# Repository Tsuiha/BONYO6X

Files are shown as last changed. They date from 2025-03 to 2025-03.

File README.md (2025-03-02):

# BONYO6X

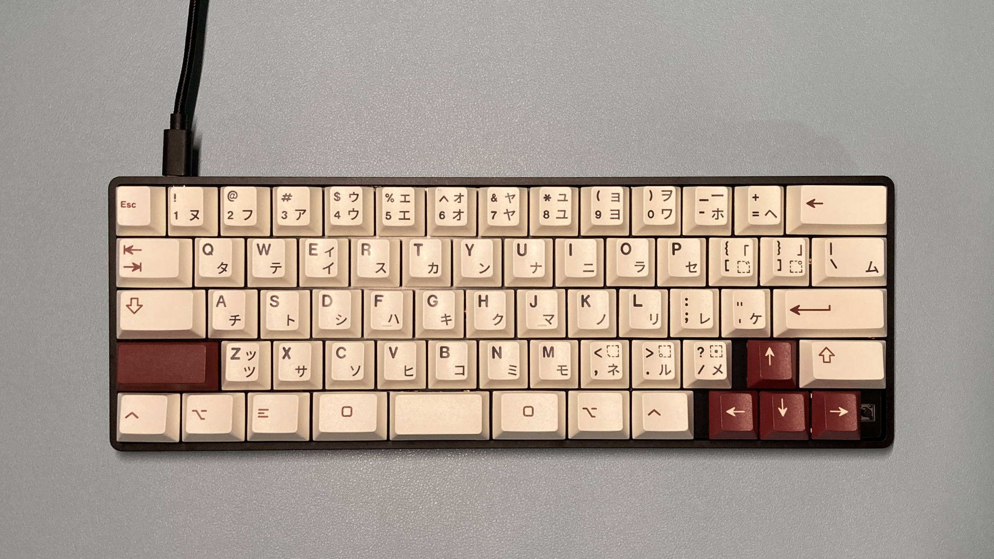
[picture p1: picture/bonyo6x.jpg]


　BONYO6Xは60%キーボードの汎用ケース、所謂Poker, GH60, DZ60等に対応したケースと互換性のあるPCBです。
 
　他人でも初見で使える, 自分でも不満なく使える, ことをコンセプトとしています。基本的なANSIは崩さずにカスタマイズ性も確保した構成を目指した、特化型でなく器用貧乏型のキーボードです。
 
　使用用途は実務からラフな普段使いまで, 一台で可もなく不可もなく, 満遍なくこなすことを想定しています。

　リポジトリに設計データが公開されています。 自由にしてください。

　[noteでも紹介しています](https://note.com/tsuiha/m/m13bdadaac60e)

## キー配置

　ANSIをベースに私の趣味を加え以下のようにカスタムしたものになります。

・2U Shift Layout  
　Row StaggeredよりもColumn StaggeredやOrtholinearが好きなこともあり、オフセット量の揃った2U Shiftの方が好みです。

・1.5U, 2U, 1.5U Thumb Cluster  
　2U スペースキーの左右に1.5U Modキーを配置し、レイヤー移動を前提とした配列としています。

・Arrow Keys  
　Arrow KeysがTop Layerにあると痒い時に手が届きます。DZ60系の詰めた配列ではなく、1.75U Shiftを端に、Arrow Keysはその内側に配置しています。

・Tactile Switch  
　キーボード右下にタクトスイッチを搭載可能です。マイクミュート, スクリーンショット, リプレイの保存 等、キースイッチと独立したFunctionキーとして使用できます。

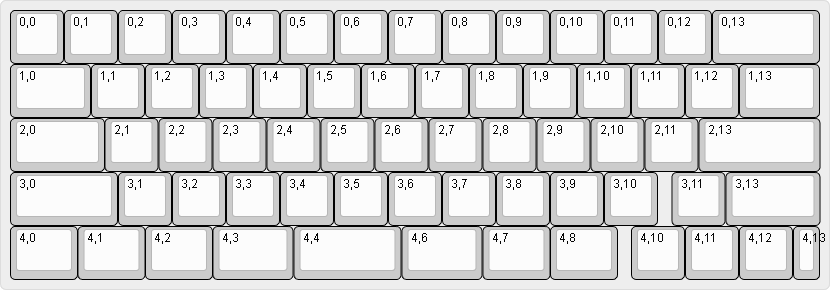
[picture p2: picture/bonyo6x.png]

画像はkeyboard-layout-editor.comにて作成しました。

## LED
　LEDが2個搭載可能です。デフォルトでは現在のレイヤーに対応して発光色が変化します。
　発光強度や色、光らせ方はファームウェアを改変し変更することができます。

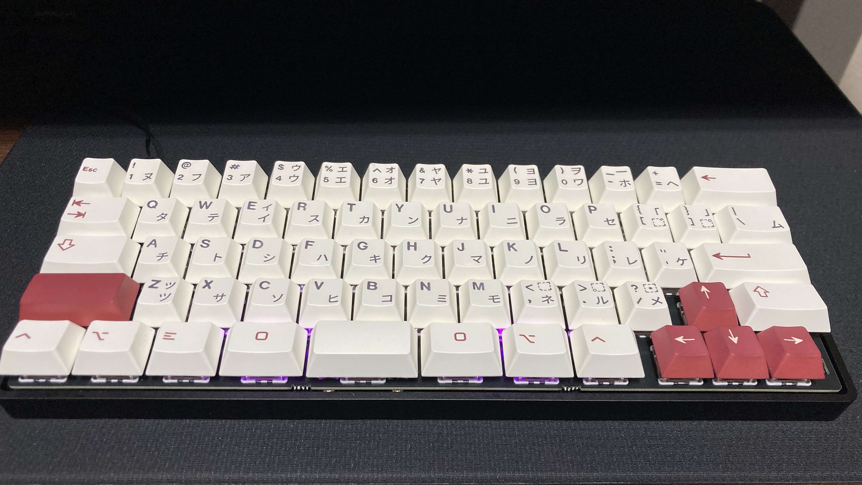
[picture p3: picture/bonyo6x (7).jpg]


## タクタイルスイッチ
　タクタイルスイッチが1個搭載可能です。ケース高に応じて高さのあったスイッチを使用してください。フローティングデザインのケースでは7mmのものを、通常デザインのケースでは11mmのものを画像では使用しています。

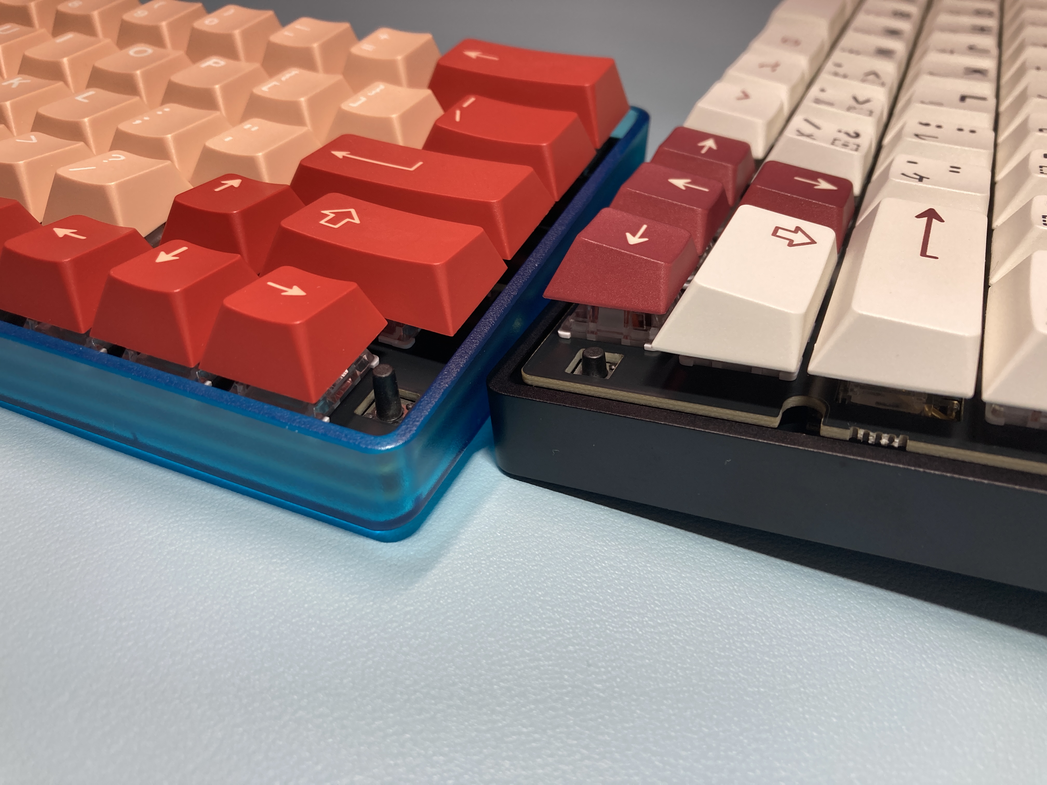
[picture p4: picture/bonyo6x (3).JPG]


# 組み立て

## PCB & Switch Plate 
　誰かが製造したものを入手するか、公開されている設計データから自身で製造ください。JLCPCBを使用する際は発注データが公開されています。

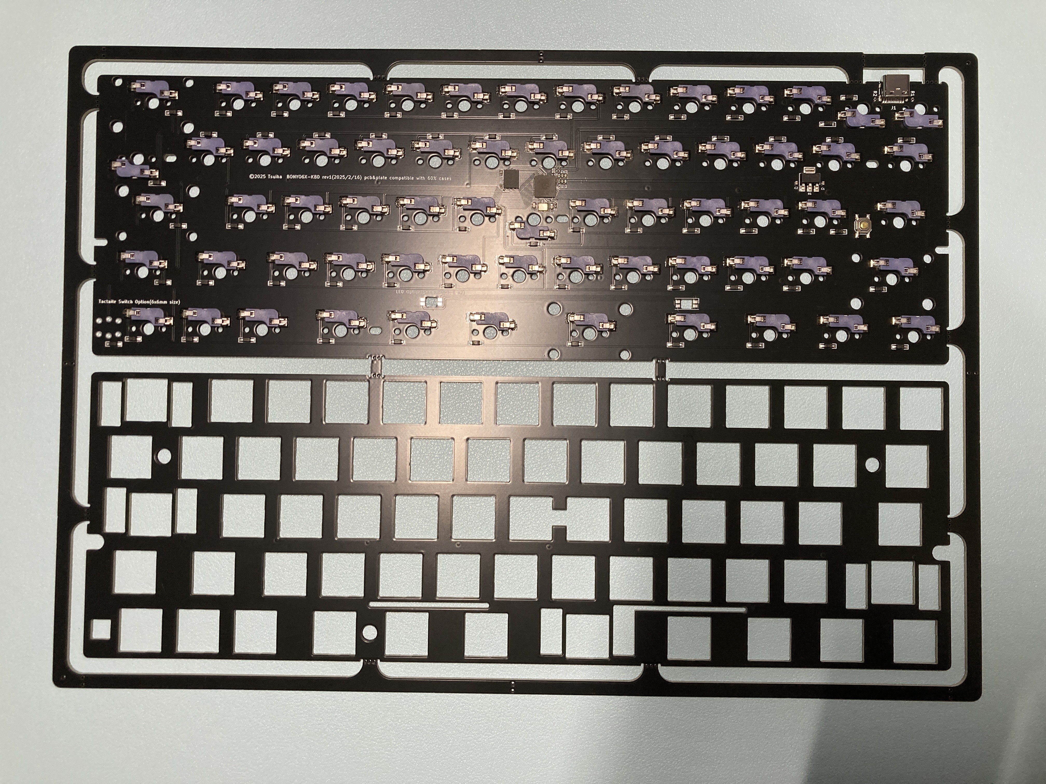
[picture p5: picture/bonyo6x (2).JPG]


## LED SK6812MINI-E x2
　オプションでLEDを取り付けることができます。



## Tactile Switch x1
　オプションでタクトスイッチを取り付けることができます。6x6mmサイズの2pinまたは4pinのものを使用することができます。





## qmk-vial
　ファームウェアにはqmk-vialを使用しています。

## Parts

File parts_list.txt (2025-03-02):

-Examples of required parts are shown below. Other compatible parts are acceptable.

Switch Plate x1
PCB x1
-There is published kicad data here

MX Switch and Keycap x 65 

Poker compatible case
-Please check the compatibility with the case on your own.

Tactile Switch x1 *option
-6x6mm type with 2 or 4 pins can be used. You can choose any height.

LED SK6812MINI-E x2 *option

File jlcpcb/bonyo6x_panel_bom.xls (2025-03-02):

Comment | Designator | Footprint | JLCPCB Part #
HRO_TYPE-C-31-M-12 | J1 | USB_C_Receptacle_HRO_TYPE-C-31-M-12 | C165948
AMS1117-3.3 | U1 | SOT-223 | C6186
rp2040 | U2 | QFN-56-1EP_7x7mm_P0.4mm_EP3.2x3.2mm | C2040
W25Q128JVPIQ | U3 | WSON-8-1EP_6x5mm_P1.27mm_EP3.4x4.3mm | C190862
Crystal_GND24 | Y1 | Crystal_SMD_3225-4Pin_3.2x2.5mm | C9002
5.1kohm | R1-2 | C_0402_1005Metric | C25905
27ohm | R3-4 | C_0402_1005Metric | C25100
1kohm | R5-6 | C_0402_1005Metric | C11702
10uF | C1-2 | C_0402_1005Metric | C315248
100nF | C3,C4,C5,C6,C9 | C_0402_1005Metric | C1525
1uF | C7-8 | C_0402_1005Metric | C52923
30pF | C10-11 | C_0603_1608Metric | C1658
SW_BOOT | SW_boot1 | SW_SPST_SKQG_WithStem | C318884
diode | D1-66 | Diode_SMD_noname | C81598
hotswapsocket | SW1-65 | CherryMX_Hotswap | CPG151101S11-16

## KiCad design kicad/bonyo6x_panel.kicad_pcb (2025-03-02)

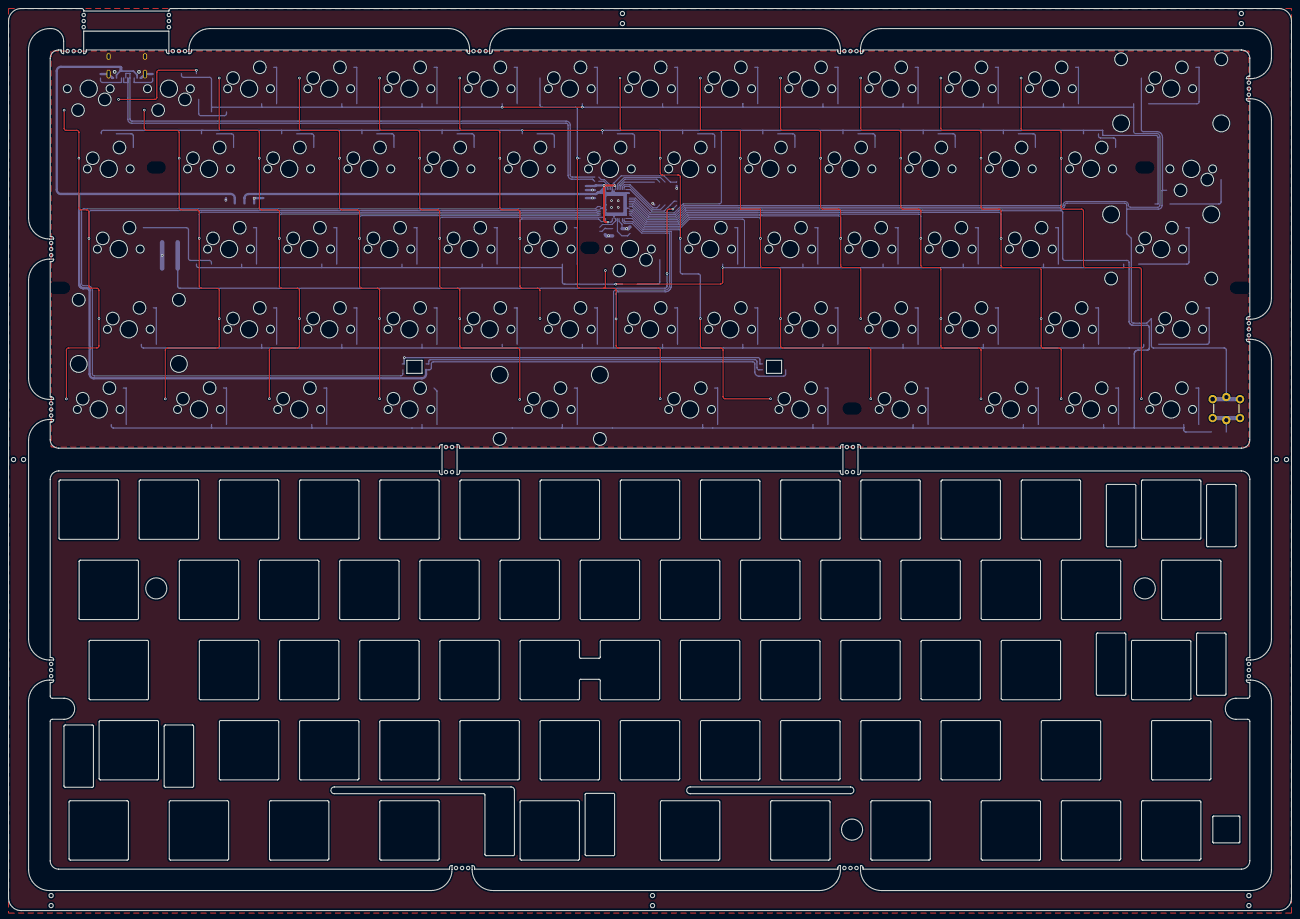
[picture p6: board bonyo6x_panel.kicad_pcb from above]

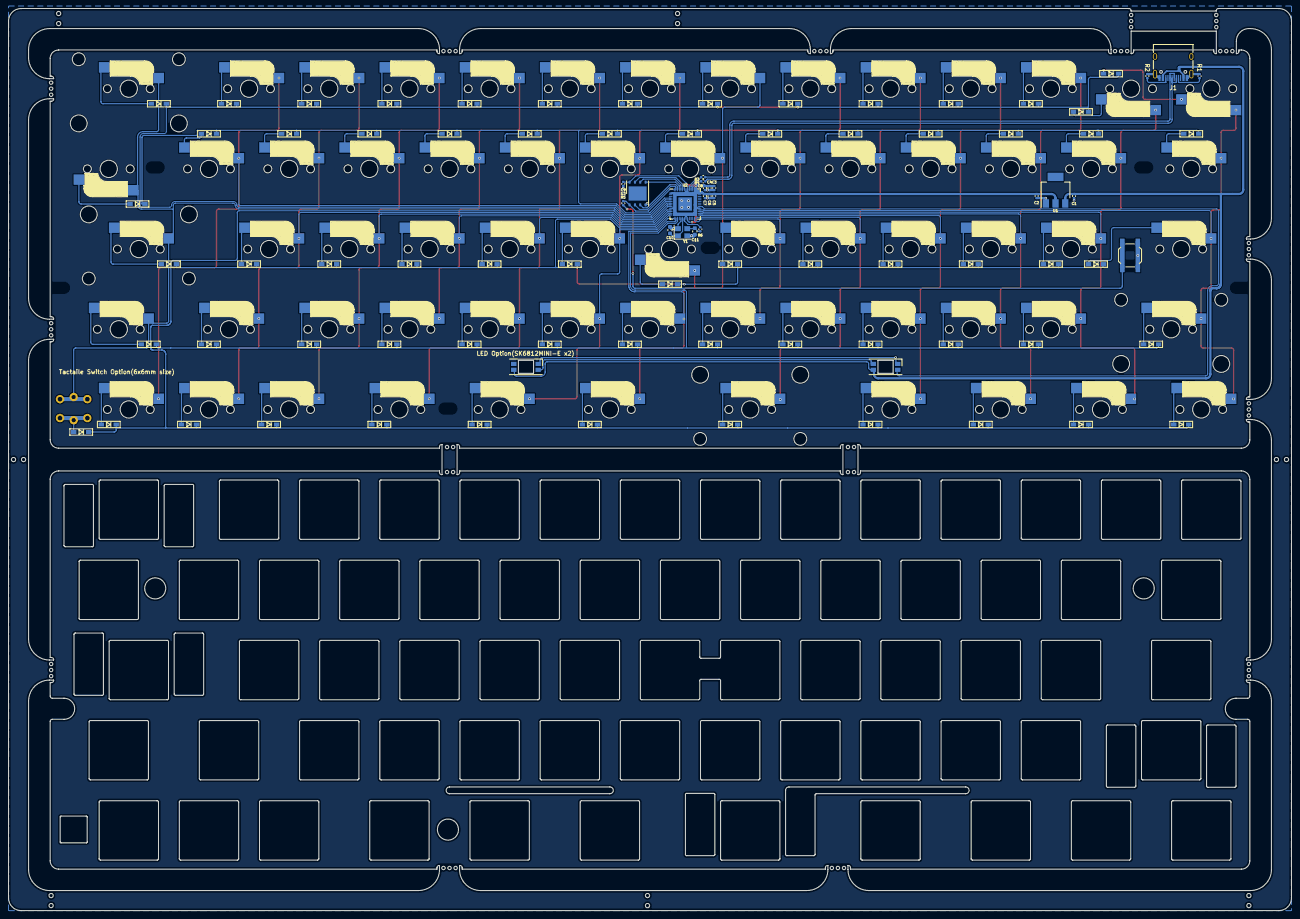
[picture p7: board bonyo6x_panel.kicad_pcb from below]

Board: 2 copper layers, 304.8 x 214.3 mm, 220 parts (25 on the bottom side), 107 nets.

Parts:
C1, C2: 10u; C_0402_1005Metric
C3, C4, C5, C6, C9: 100n; C_0402_1005Metric
C7, C8: 1u; C_0402_1005Metric
C10, C11: 30p; C_0603_1608Metric
D1, D2, D3, D4, D5, D6, D7, D8, D9, D10, D11, D12, D13, D14, D15, D16, D17, D18, D19, D20, D21, D22, D23, D24, D25, D26, D27, D28, D29, D30, D31, D32, D33, D34, D35, D36, D37, D38, D39, D40, D41, D42, D43, D44, D45, D46, D47, D48, D49, D50, D51, D52, D53, D54, D55, D56, D57, D58, D59, D60, D61, D62, D63, D64, D65, D66: D; Diode_SMD_noname
J1: USB_C_Receptacle; USB_C_Receptacle_HRO_TYPE-C-31-M-12
LED1, LED2: YS-SK6812MINI-E
R1, R2: 5.1k; C_0402_1005Metric
R3, R4: 27; C_0402_1005Metric
R5, R6: 1k; C_0402_1005Metric
SW1, SW2#2, SW3, SW4#2, SW5, SW6, SW7#2, SW8#2, SW9#2, SW10, SW11#2, SW12, SW13#2, SW16, SW17, SW18#2, SW19, SW20, SW21#2, SW22#2, SW23, SW24, SW25, SW26, SW27, SW30, SW31, SW32, SW33#2, SW34, SW35, SW36, SW37#2, SW38#2, SW39, SW40#2, SW43#2, SW44, SW45#2, SW46, SW47, SW48#2, SW49, SW50#2, SW51#2, SW52#2, SW53, SW63, SW64#2, SW65: SW_PUSH; CherryMX_Hotswap
SW1#2, SW2, SW3#2, SW4, SW5#2, SW6#2, SW7, SW8, SW9, SW10#2, SW11, SW12#2, SW13, SW16#2, SW17#2, SW18, SW19#2, SW20#2, SW21, SW22, SW23#2, SW24#2, SW25#2, SW26#2, SW27#2, SW30#2, SW31#2, SW32#2, SW33, SW36#2, SW37, SW38, SW39#2, SW40, SW43, SW44#2, SW45, SW46#2, SW47#2, SW48, SW49#2, SW50, SW51, SW52, SW53#2, SW63#2, SW64, SW65#2: SW_PUSH; SW_Hole_1u
SW14: SW_PUSH_2; SW_Hole_2u
SW14#2: SW_PUSH_2; CherryMX_Hotswap_2u
SW15, SW28, SW58#2, SW60, SW60#3: SW_PUSH_15; SW_Hole_1u
SW15#2, SW28#2, SW58, SW60#2: SW_PUSH_15; CherryMX_Hotswap_1.5u
SW29, SW54#2: SW_PUSH_175; CherryMX_Hotswap_1.75u
SW29#2, SW54: SW_PUSH_175; SW_Hole_1u
SW41: SW_PUSH_225; CherryMX_Hotswap_2u_r
SW41#2, SW42: SW_PUSH_225; SW_Hole_2u
SW42#2: SW_PUSH_225; CherryMX_Hotswap_2u
SW55, SW56#2, SW57, SW61, SW62#2: SW_PUSH_125; CherryMX_Hotswap_1.25u
SW55#2, SW56, SW57#2, SW61#2, SW62: SW_PUSH_125; SW_Hole_1u
SW59: SW_PUSH_2; CherryMX_Hotswap_2u_r
SW_boot1: SW_BOOT; SW_SPST_SKQG_WithStem
SW_tact1: SW_PUSH; tactileforkh60
U1: AMS1117-3.3; SOT-223
U2: RP2040; QFN-56-1EP_7x7mm_P0.4mm_EP3.2x3.2mm
U3: W25Q128JVS; WSON-8-1EP_6x5mm_P1.27mm_EP3.4x4.3mm
Y1: Crystal_GND24; Crystal_SMD_3225-4Pin_3.2x2.5mm

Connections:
+1V1: C3.1, C4.1, C8.1, U2.23 (DVDD), U2.45 (VREG_VOUT), U2.50 (DVDD)
+3V3: C2.1, C5.1, C6.1, C7.1, C9.1, U1.2 (VO), U2.1 (IOVDD), U2.10 (IOVDD), U2.22 (IOVDD), U2.33 (IOVDD), U2.42 (IOVDD), U2.43 (ADC_AVDD), U2.44 (VREG_IN), U2.48 (USB_VDD), U2.49 (IOVDD), U3.8 (VCC)
+5V: C1.1, J1.A4 (VBUS), J1.A9 (VBUS), J1.B4 (VBUS), J1.B9 (VBUS), LED1.1 (VDD), LED2.1 (VDD), U1.3 (VI)
/QSPI_SCLK: U2.52 (QSPI_SCLK), U3.6 (CLK)
/QSPI_SD0: U2.53 (QSPI_SD0), U3.5 (DI(IO0))
/QSPI_SD1: U2.55 (QSPI_SD1), U3.2 (DO(IO1))
/QSPI_SD2: U2.54 (QSPI_SD2), U3.3 (IO2)
/QSPI_SD3: U2.51 (QSPI_SD3), U3.7 (IO3)
/QSPI_SS: R5.1, U2.56 (QSPI_SS), U3.1 (~CS)
/USB_D+: J1.A6 (D+), J1.B6 (D+), R3.2
/USB_D-: J1.A7 (D-), J1.B7 (D-), R4.2
/XIN: C10.2, U2.20 (XIN), Y1.1
/XOUT: R6.1, U2.21 (XOUT)
/~USB_BOOT: R5.2, SW_boot1.1
GND: C1.2, C2.2, C3.2, C4.2, C5.2, C6.2, C7.2, C8.2, C9.2, C10.1, C11.2, J1.A1 (GND), J1.A12 (GND), J1.B1 (GND), J1.B12 (GND), J1.S1 (SHIELD), LED1.3 (VSS), LED2.3 (VSS), R1.1, R2.1, SW_boot1.2, U1.1 (GND), U2.19 (TESTEN), U2.57 (GND), U3.4 (GND), Y1.2, Y1.4
LED: LED1.4 (DIN), U2.34 (GPIO22)
unnamed: C11.1, R6.2, Y1.3
unnamed: D1.2 (A), SW1.1
unnamed: D2.2 (A), SW2#2.1
unnamed: D3.2 (A), SW3.2
unnamed: D4.2 (A), SW4#2.2
unnamed: D5.2 (A), SW5.2
unnamed: D6.2 (A), SW6.2
unnamed: D7.2 (A), SW7#2.2
unnamed: D8.2 (A), SW8#2.2
unnamed: D9.2 (A), SW9#2.2
unnamed: D10.2 (A), SW10.2
unnamed: D11.2 (A), SW11#2.2
unnamed: D12.2 (A), SW12.2
unnamed: D13.2 (A), SW13#2.2
unnamed: D14.2 (A), SW14#2.2
unnamed: D15.2 (A), SW15#2.2
unnamed: D16.2 (A), SW16.2
unnamed: D17.2 (A), SW17.2
unnamed: D18.2 (A), SW18#2.2
unnamed: D19.2 (A), SW19.2
unnamed: D20.2 (A), SW20.2
unnamed: D21.2 (A), SW21#2.2
unnamed: D22.2 (A), SW22#2.2
unnamed: D23.2 (A), SW23.2
unnamed: D24.2 (A), SW24.2
unnamed: D25.2 (A), SW25.2
unnamed: D26.2 (A), SW26.2
unnamed: D27.2 (A), SW27.2
unnamed: D28.2 (A), SW28#2.1
unnamed: D29.2 (A), SW29.2
unnamed: D30.2 (A), SW30.2
unnamed: D31.2 (A), SW31.2
unnamed: D32.2 (A), SW32.2
unnamed: D33.2 (A), SW33#2.2
unnamed: D34.2 (A), SW34.2
unnamed: D35.2 (A), SW35.1
unnamed: D36.2 (A), SW36.2
unnamed: D37.2 (A), SW37#2.2
unnamed: D38.2 (A), SW38#2.2
unnamed: D39.2 (A), SW39.2
unnamed: D40.2 (A), SW40#2.2
unnamed: D41.2 (A), SW41.2
unnamed: D42.2 (A), SW42#2.2
unnamed: D43.2 (A), SW43#2.2
unnamed: D44.2 (A), SW44.2
unnamed: D45.2 (A), SW45#2.2
unnamed: D46.2 (A), SW46.2
unnamed: D47.2 (A), SW47.2
unnamed: D48.2 (A), SW48#2.2
unnamed: D49.2 (A), SW49.2
unnamed: D50.2 (A), SW50#2.2
unnamed: D51.2 (A), SW51#2.2
unnamed: D52.2 (A), SW52#2.2
unnamed: D53.2 (A), SW53.2
unnamed: D54.2 (A), SW54#2.2
unnamed: D55.2 (A), SW55.2
unnamed: D56.2 (A), SW56#2.2
unnamed: D57.2 (A), SW57.2
unnamed: D58.2 (A), SW58.2
unnamed: D59.2 (A), SW59.2
unnamed: D60.2 (A), SW60#2.2
unnamed: D61.2 (A), SW61.2
unnamed: D62.2 (A), SW62#2.2
unnamed: D63.2 (A), SW63.2
unnamed: D64.2 (A), SW64#2.2
unnamed: D65.2 (A), SW65.2
unnamed: D66.2 (A), SW_tact1.2
unnamed: J1.A5 (CC1), R1.2
unnamed: J1.B5 (CC2), R2.2
unnamed: LED1.2 (DOUT), LED2.4 (DIN)
unnamed: R4.1, U2.46 (USB_DM)
unnamed: R3.1, U2.47 (USB_DP)
c0: SW1.2, SW15#2.1, SW29.1, SW42#2.1, SW55.1, U2.32 (GPIO21)
c1: SW2#2.2, SW16.1, SW30.1, SW43#2.1, SW56#2.1, U2.31 (GPIO20)
c2: SW3.1, SW17.1, SW31.1, SW44.1, SW57.1, U2.30 (GPIO19)
c3: SW4#2.1, SW18#2.1, SW32.1, SW45#2.1, SW58.1, U2.29 (GPIO18)
c4: SW5.1, SW19.1, SW33#2.1, SW46.1, SW59.1, U2.28 (GPIO17)
c5: SW6.1, SW20.1, SW34.1, SW47.1, U2.27 (GPIO16)
c6: SW7#2.1, SW21#2.1, SW35.2, SW48#2.1, SW60#2.1, U2.16 (GPIO13)
c7: SW8#2.1, SW22#2.1, SW36.1, SW49.1, SW61.1, U2.15 (GPIO12)
c8: SW9#2.1, SW23.1, SW37#2.1, SW50#2.1, SW62#2.1, U2.13 (GPIO10)
c9: SW10.1, SW24.1, SW38#2.1, SW51#2.1, U2.12 (GPIO9)
c10: SW11#2.1, SW25.1, SW39.1, SW52#2.1, SW63.1, U2.11 (GPIO8)
c11: SW12.1, SW26.1, SW40#2.1, SW53.1, SW64#2.1, U2.9 (GPIO7)
c12: SW13#2.1, SW27.1, SW65.1, U2.5 (GPIO3)
c13: SW14#2.1, SW28#2.2, SW41.1, SW54#2.1, SW_tact1.1, U2.7 (GPIO5)
r0: D1.1 (K), D2.1 (K), D3.1 (K), D4.1 (K), D5.1 (K), D6.1 (K), D7.1 (K), D8.1 (K), D9.1 (K), D10.1 (K), D11.1 (K), D12.1 (K), D13.1 (K), D14.1 (K), U2.6 (GPIO4)
r1: D15.1 (K), D16.1 (K), D17.1 (K), D18.1 (K), D19.1 (K), D20.1 (K), D21.1 (K), D22.1 (K), D23.1 (K), D24.1 (K), D25.1 (K), D26.1 (K), D27.1 (K), D28.1 (K), U2.4 (GPIO2)
r2: D29.1 (K), D30.1 (K), D31.1 (K), D32.1 (K), D33.1 (K), D34.1 (K), D35.1 (K), D36.1 (K), D37.1 (K), D38.1 (K), D39.1 (K), D40.1 (K), D41.1 (K), U2.14 (GPIO11)
r3: D42.1 (K), D43.1 (K), D44.1 (K), D45.1 (K), D46.1 (K), D47.1 (K), D48.1 (K), D49.1 (K), D50.1 (K), D51.1 (K), D52.1 (K), D53.1 (K), D54.1 (K), U2.17 (GPIO14)
r4: D55.1 (K), D56.1 (K), D57.1 (K), D58.1 (K), D59.1 (K), D60.1 (K), D61.1 (K), D62.1 (K), D63.1 (K), D64.1 (K), D65.1 (K), D66.1 (K), U2.8 (GPIO6)
